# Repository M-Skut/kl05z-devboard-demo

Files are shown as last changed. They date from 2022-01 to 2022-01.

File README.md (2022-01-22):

# KL-05 DevBoard Demo project with simple HAL

## Hardware
To make development of advanced microcontroller projects simple, the DevBoard is equipped with following features:
- SD Card slot
- 6-button keypad connected as analog input
- stylophone-like keyboard as analog input
- PMOD Interface Type 2 (SPI)
- MikroBus Connector
- 3x WS2812B addressable RGB LEDs
- connector for Nokia 5510 display board
- buzzer
- fused 3V3 and 5V lines
- connector for Adafruit ALS-PT19 Analog Light Sensor Breakout
- connector for 16x2 LCD with I2C adapter
- 25LCxxx SPI Flash
- 2x 24Cxx I2C Flash
- RTC clock with battery based on PCF8563 RTC IC with I2C interface
- LM75 I2C temperature sensor

## Some photos of the hardware (more in `media` folder)

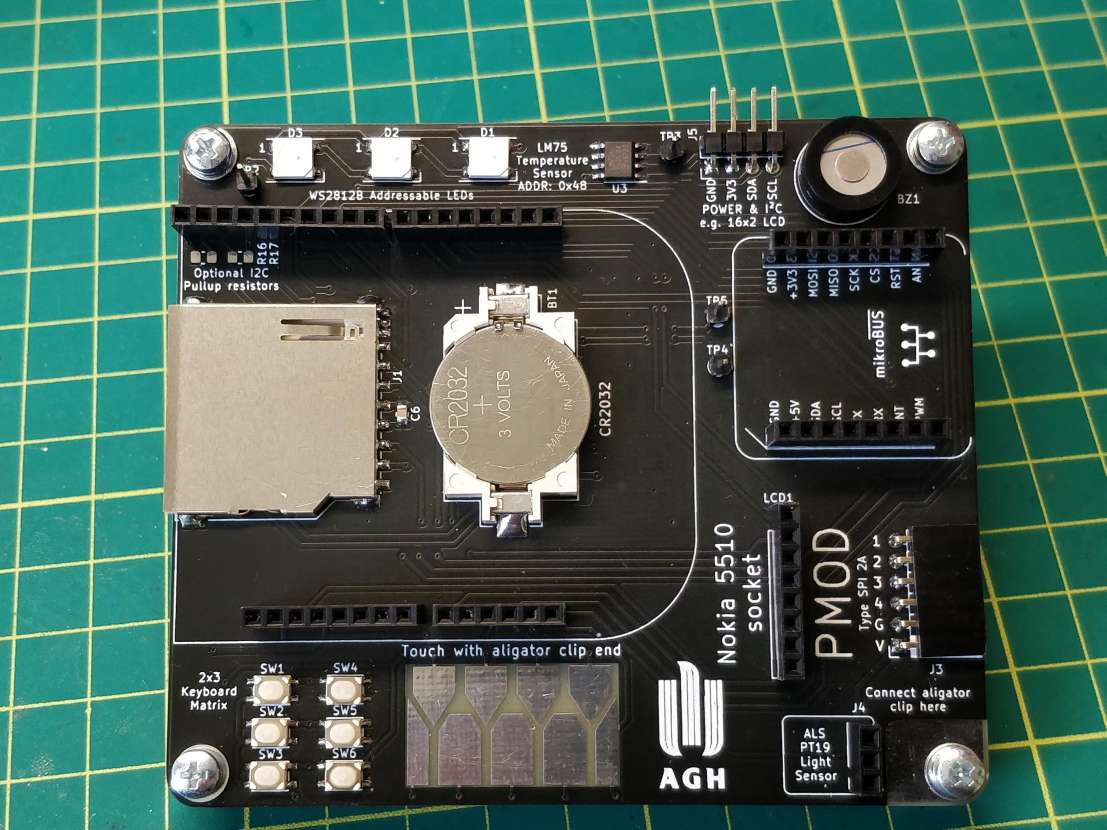
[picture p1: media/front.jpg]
Front of the PCB

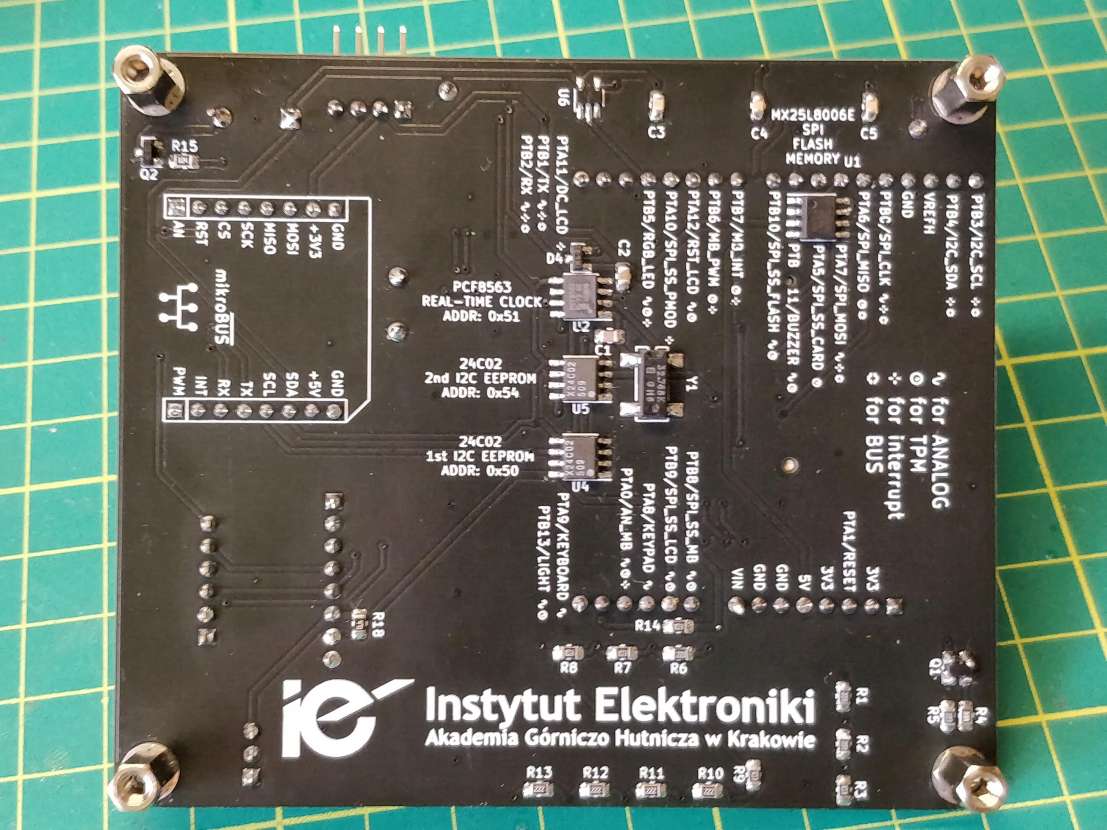
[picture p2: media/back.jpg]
Back of the PCB


## Bill Of Materials
Interactive Bill Of Materials for the newest revision of the hardware can be found [here](frdm05-devboard-hardware/bom/ibom.html)

#### Hardware revision history
Rev. 1:
- first revision of hardware
Rev. 2:
- fix for analog keypad (wrong placement of current mirror)
- addition of current-limiting resistor for buzzer
- addition of optional fuses for 3V3 and 5V lines
Rev. 2.1:
- fix for 3V3 fuse
- fix for buzzer footprint
- fix for some silkscreen areas
Rev. 2.2:
- change 74HCT1G125GV buffer to faster 74AHCT1G125GV version

## Environment
To develop this demonstration project, following set of tools and programs was used:
- [Visual Studio Code](https://code.visualstudio.com/) with plugins:
    - [`Cortex Debug`](https://marketplace.visualstudio.com/items?itemName=marus25.cortex-debug) from `marus25`
    - [`CMake Tools`](https://marketplace.visualstudio.com/items?itemName=ms-vscode.cmake-tools) from `microsoft`
- GNU GCC ARM Compiler from Official ARM Distribution
- SEGGER JLINK
- CMake
- Ninja
- (Optional) ARM Compiler 5 from Keil
- (Optional) Doxygen

### How to install it on Windows
- Install GCC from [Official ARM Distribution](https://developer.arm.com/tools-and-software/open-source-software/developer-tools/gnu-toolchain/gnu-rm/downloads) and **check "Add to PATH"** when installing
- Install [CMake](https://cmake.org/download/), also **Add to PATH** when installing
- Install [J-Link Software and Documentation pack](https://www.segger.com/downloads/jlink/)
- Download [Ninja](https://github.com/ninja-build/ninja/releases) and put it into some folder in PATH, for example in `C:\Program Files\CMake\bin`
- [Install Visual Studio Code](https://code.visualstudio.com/download) and its extensions
- (Optional) Install [Doxygen](https://www.doxygen.nl/download.html) for generating documentation

### How to install it on other operating systems
- Install the required software from author's website or from OS repositories.

Now you can open the project folder. Select GNU toolchain as CMake kit when asked and edit file `launch.json` inside `.vscode` folder if your `JLinkGDBServer` location is different than he one used in this project. For ARM Compiler 5.06 toolchain,
an environment variable `ARMCC_TOOLCHAIN_PATH` has to be set to `bin` folder of the toolchain files. Alternatively, `armcc.cmake` file inside `toolchain-conf` can be edited to make te path setting permanent.

### Environment features
- two-click switch between ARM Compiler 5 and GCC Compiler
- all code editing features that Visual Studio Code has to offer
- easy debugging of compiled code
- two-click generation of doxygen HTML documentation
- built-in git integration
- works on Windows, GNU/Linux and Mac OS (or at least should)

## HAL
This simple hardware abstraction layer is based on two sources: KL05 Sample Code Package
from Freescale and MBED platform-specific code for KLXX targets. The C API relies
on heavy use of custom enums and structs to ensure that invalid function parameters can be found in
compilation stage. It uses C99 features (`stdint.h`, `stdbool.h`, in-place struct 
initialization etc.) and was tested with GCC 11 compiler and ARM 5.06 Compiler, but should
be compiler-independent, as it does not use compiler-dependent features directly, but instead it's using
CMSIS functions as abstraction layer.

### Goals:
- Prevent user from error-prone and hard-to-debug manual peripheral register setting
- Simple and straightforward for both understanding the underlying code and using the API
- Versatile - use for all applications within this uC
- Smallish footprint
- Separated device drivers from mcu peripheral drivers (exceptions only for very timing-sensitive devices)
- User-proof, mostly
- Peripherals can be reinitialized and will still work
- Communication peripheral drivers can be used without gpio driver
- Supports any MCU working frequency 

### Non-goals:
- universal
- unified (in GPIO mapping, same peripheral but more instances etc.)

### Drivers features:
#### UART:
- different pinout configuration
- automatic calculation for baudrate with ability to re-init if CPU speed changes
- error if configuration baudrate or pins cannot be set
- simple print, putchar and getchar API
- RX IRQ callback setting and checking RX overrun

#### I2C:
- different pinout configuration
- different speed selection
- timeout detection in all functions
- included fix for silicon errata
  
#### GPIO
- bare-bones abstraction of the register setting
- interrupt with callback functions
- inline functions for fast pin setting

#### Delay
- SysTick-based delay
- works without affecting SysTick settings
- based on delay code from u8g2 project

#### ADC
- ADC calibration function
- simple 16-bit value read
- uses `gpio` driver for pin mapping
- ADC presets (currently only one available)

#### PWM
- TPM-based PWM
- uses `gpio` driver for pin mapping
- allows setting period and pulse width in microseconds or as raw values

#### WS2812
- currently only GCC supported
- based on [cpldcpu's WS2812 ARM bitbang driver](https://github.com/cpldcpu/light_ws2812/blob/master/light_ws2812_ARM/light_ws2812_cortex.c)

#### MMA8451Q
- range setting
- conversion to float values

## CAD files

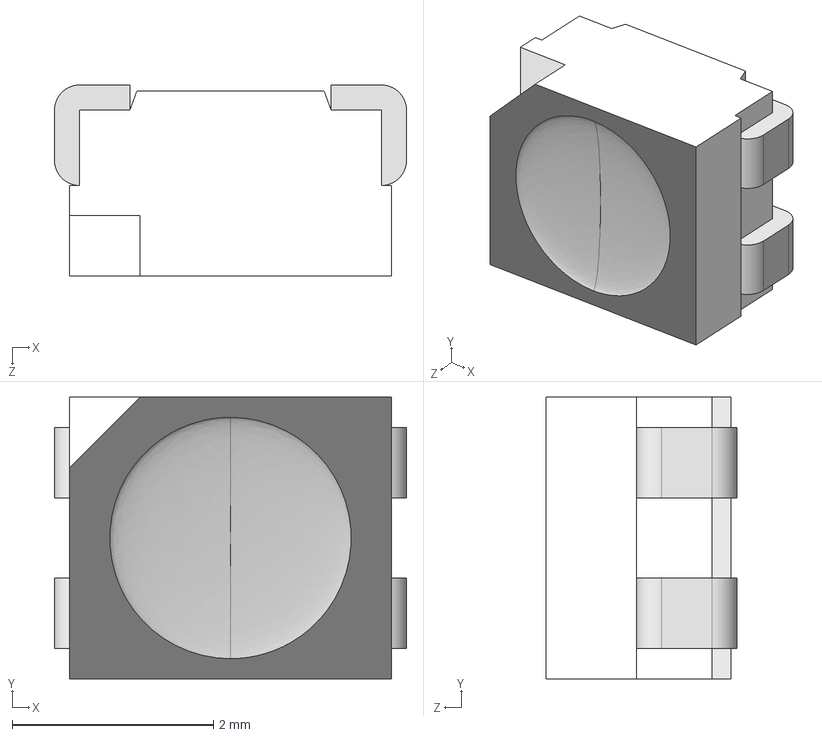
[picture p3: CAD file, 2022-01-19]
frdm05-devboard-hardware/FRDM-KL05Z-Mockup/led.step
3.50 x 2.80 x 1.90 mm

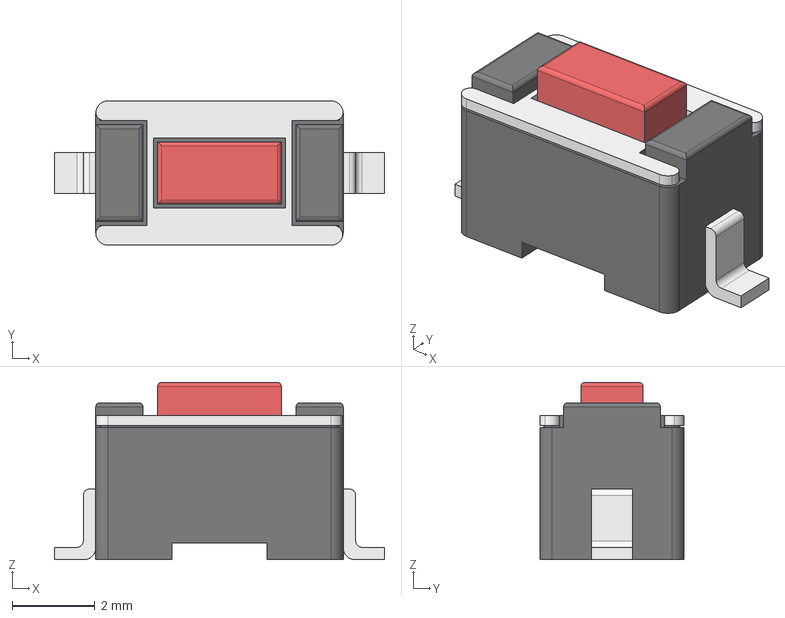
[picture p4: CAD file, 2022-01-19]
frdm05-devboard-hardware/FRDM-KL05Z-Mockup/switch.step
8.00 x 3.50 x 4.30 mm

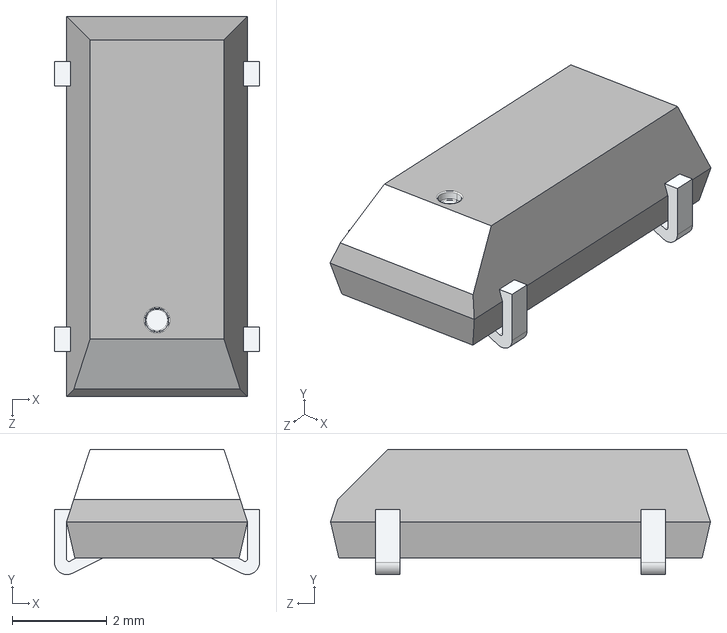
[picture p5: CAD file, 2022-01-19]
frdm05-devboard-hardware/FRDM-KL05Z-Mockup/crystal.step
4.32 x 2.63 x 8.00 mm

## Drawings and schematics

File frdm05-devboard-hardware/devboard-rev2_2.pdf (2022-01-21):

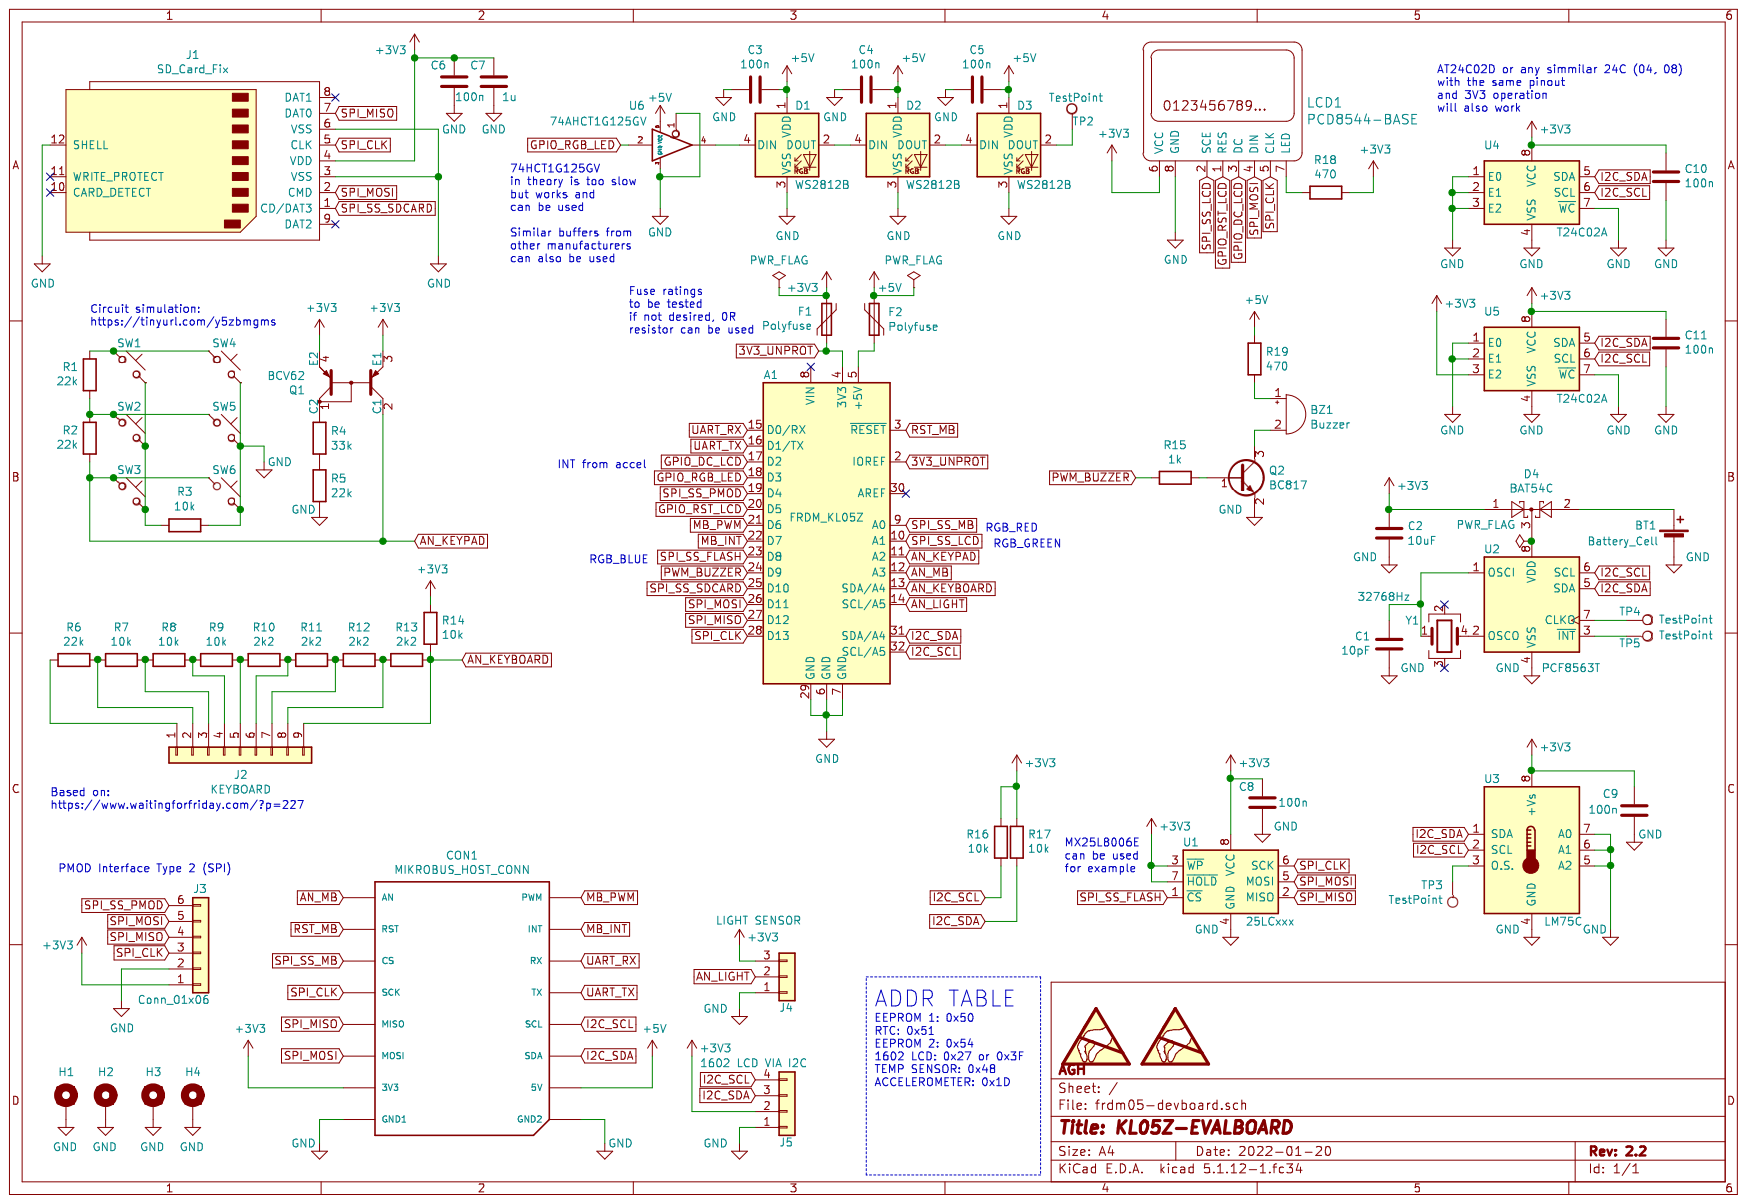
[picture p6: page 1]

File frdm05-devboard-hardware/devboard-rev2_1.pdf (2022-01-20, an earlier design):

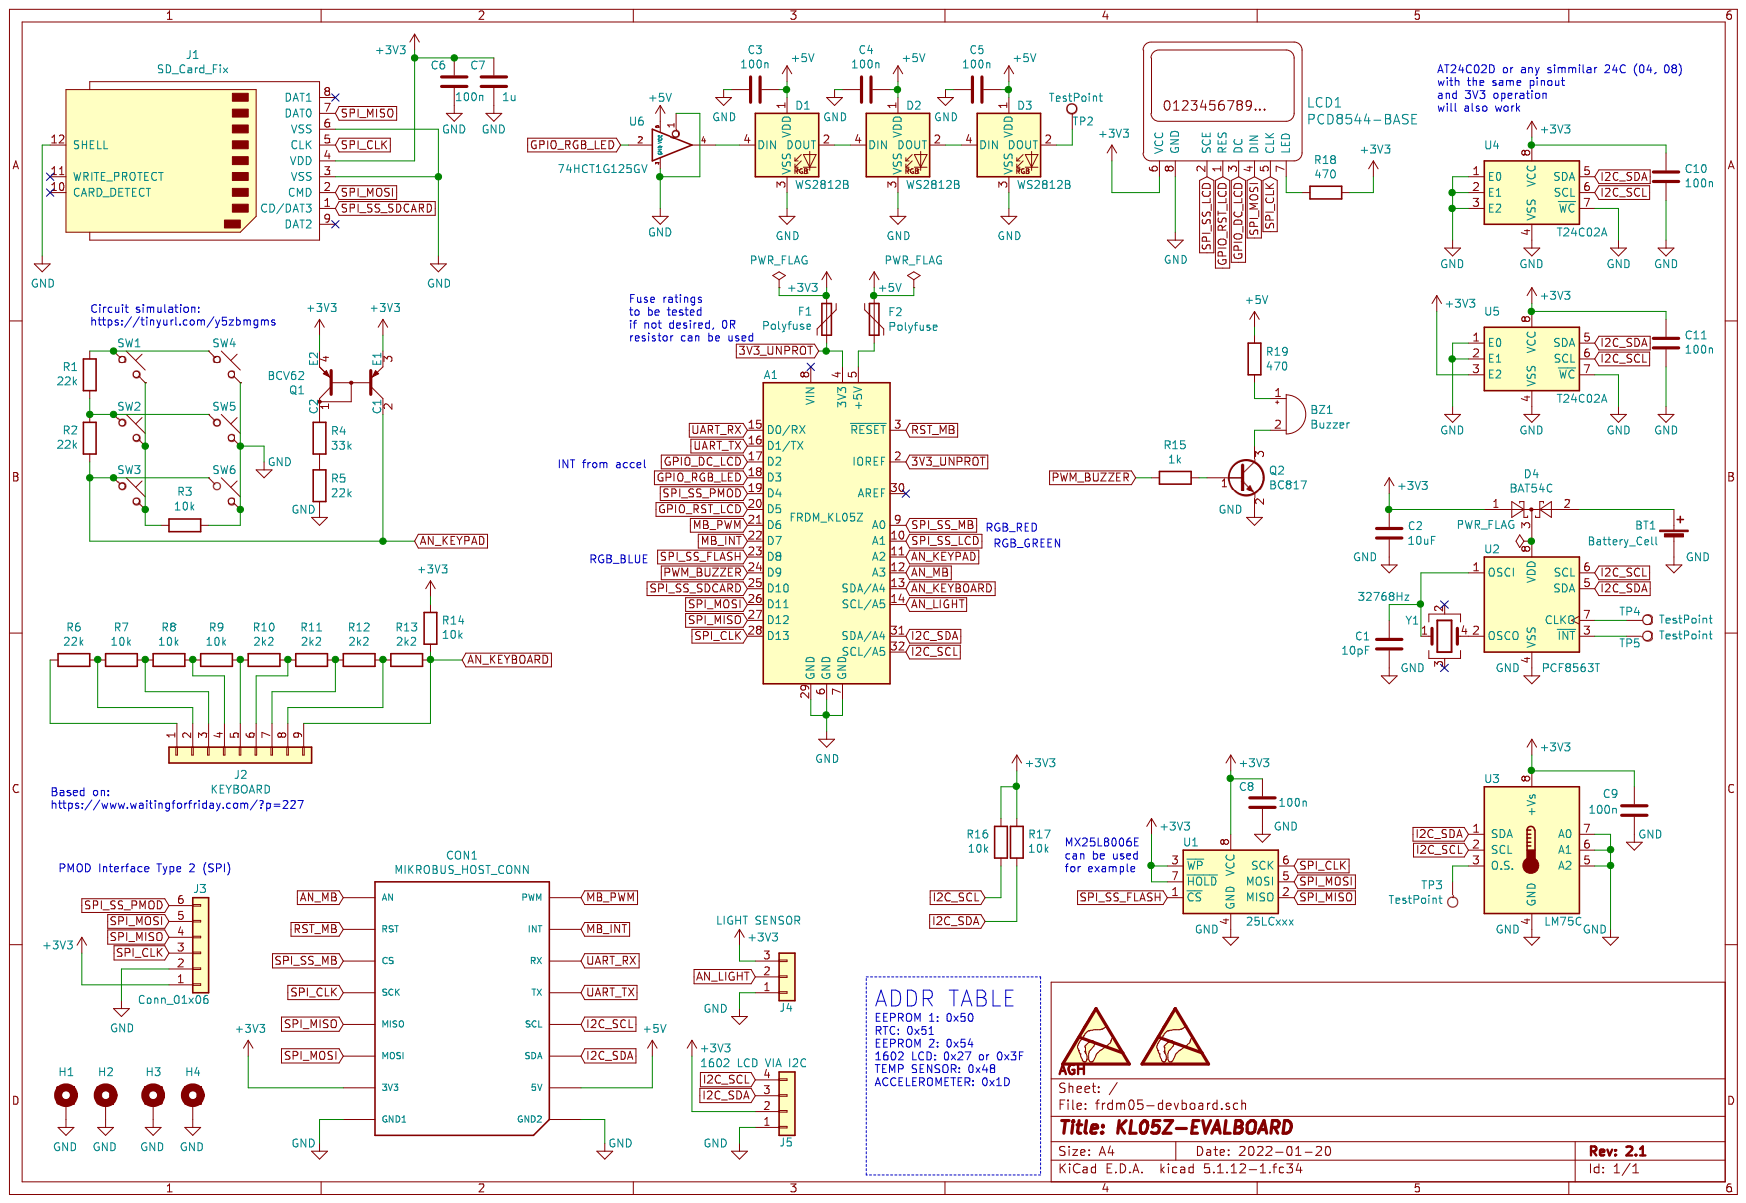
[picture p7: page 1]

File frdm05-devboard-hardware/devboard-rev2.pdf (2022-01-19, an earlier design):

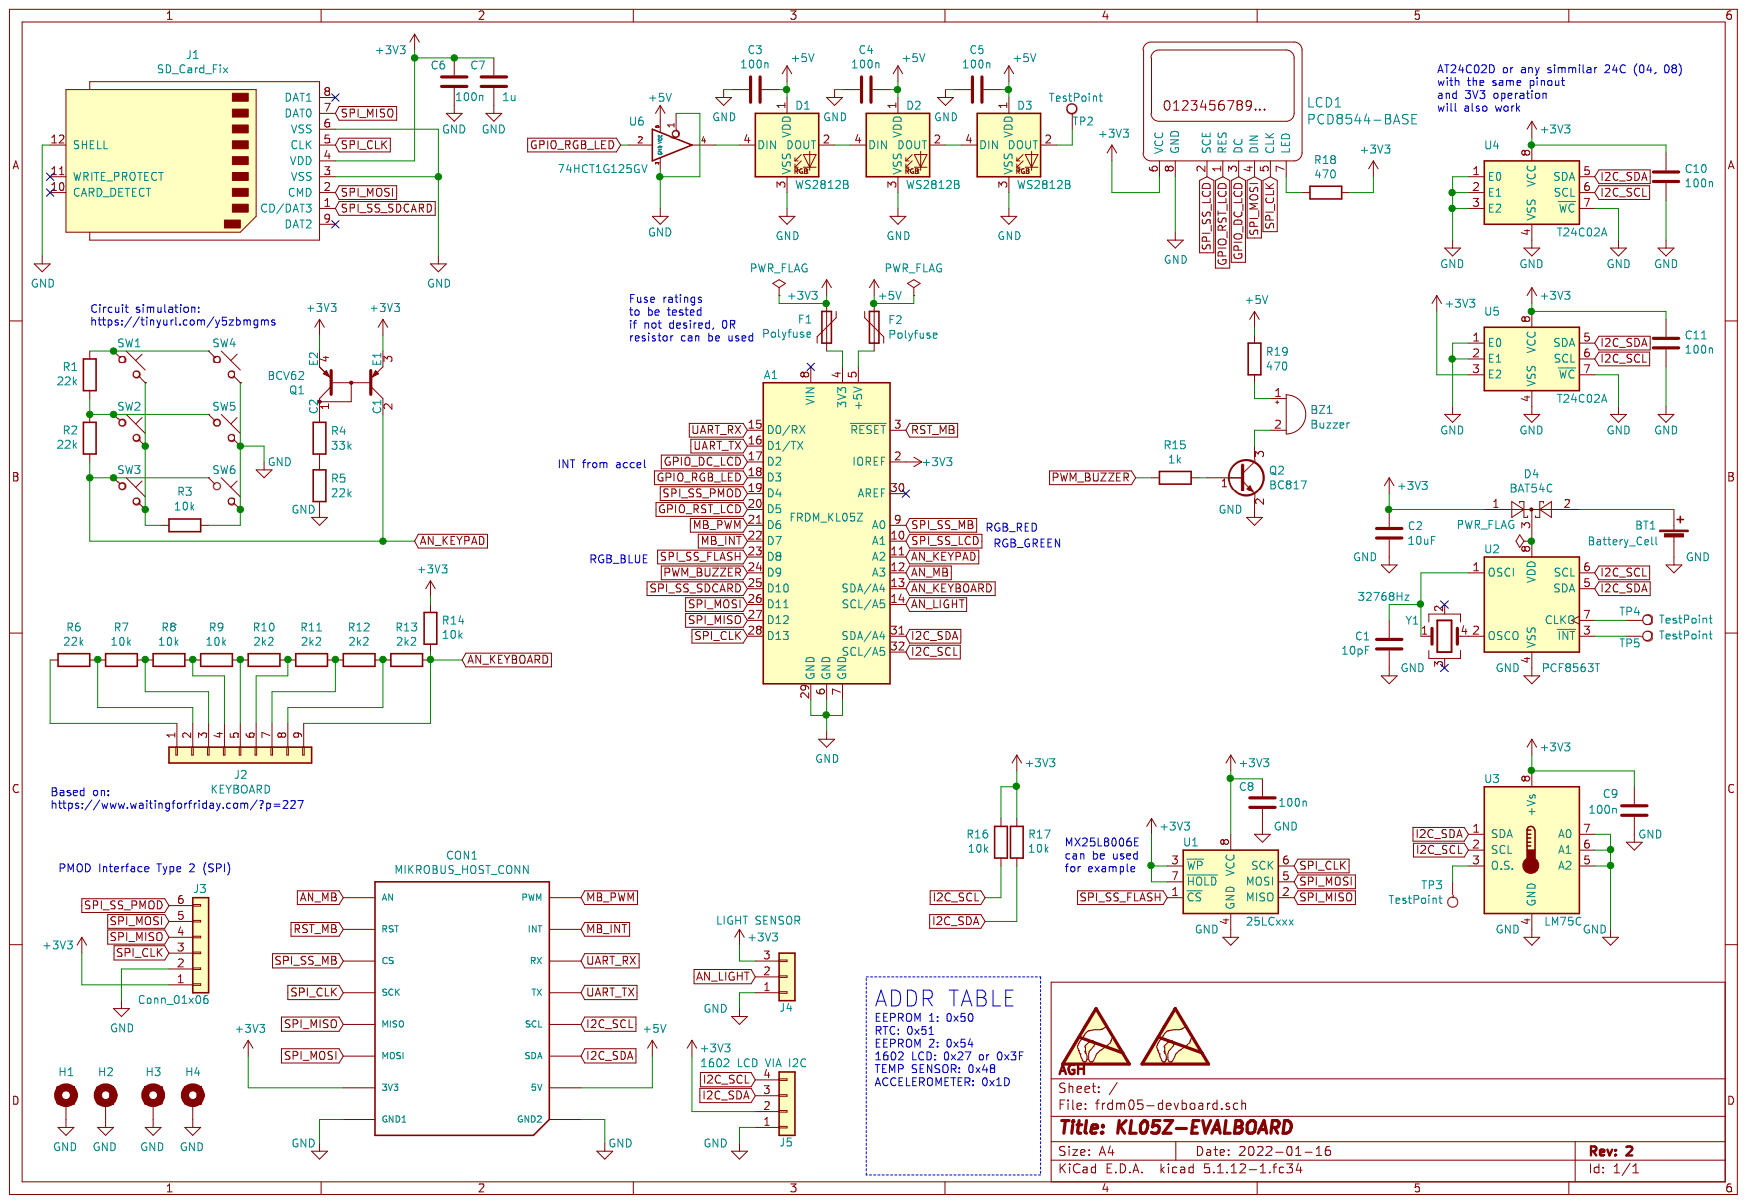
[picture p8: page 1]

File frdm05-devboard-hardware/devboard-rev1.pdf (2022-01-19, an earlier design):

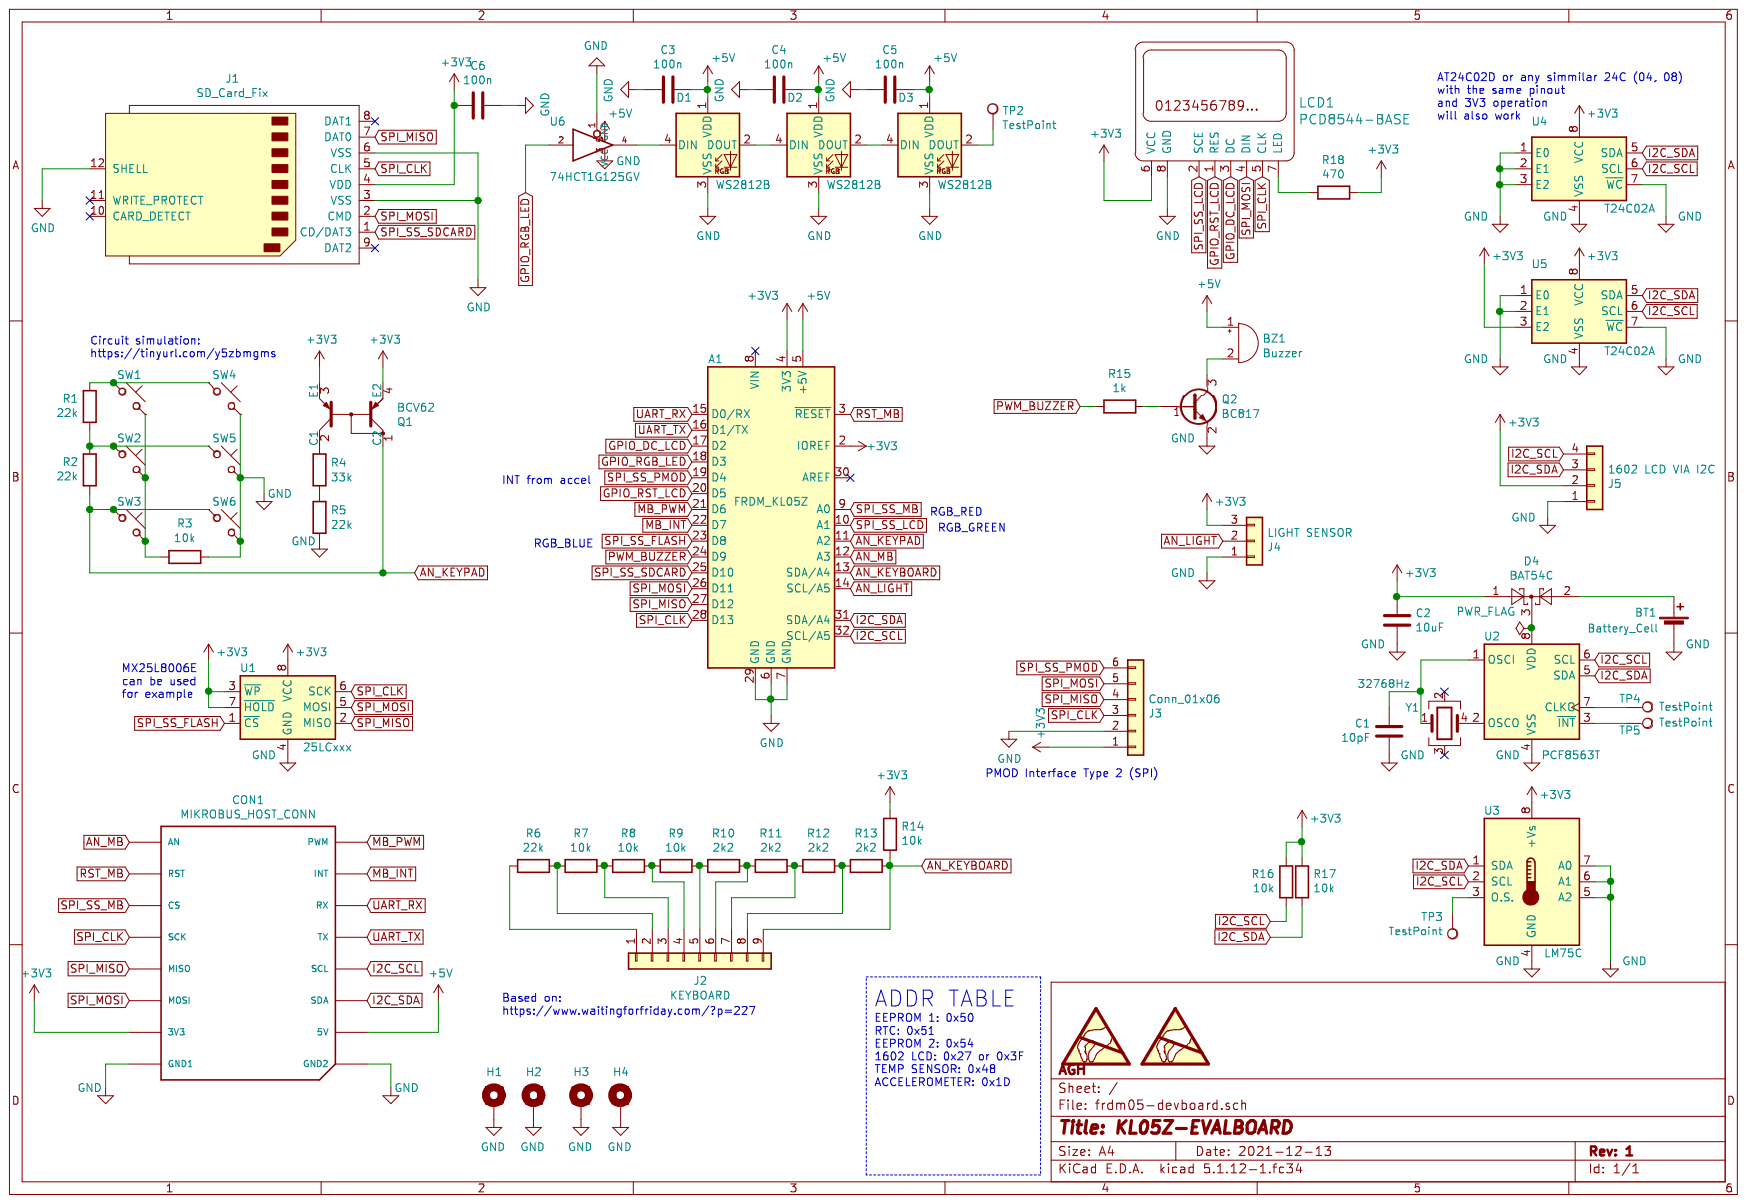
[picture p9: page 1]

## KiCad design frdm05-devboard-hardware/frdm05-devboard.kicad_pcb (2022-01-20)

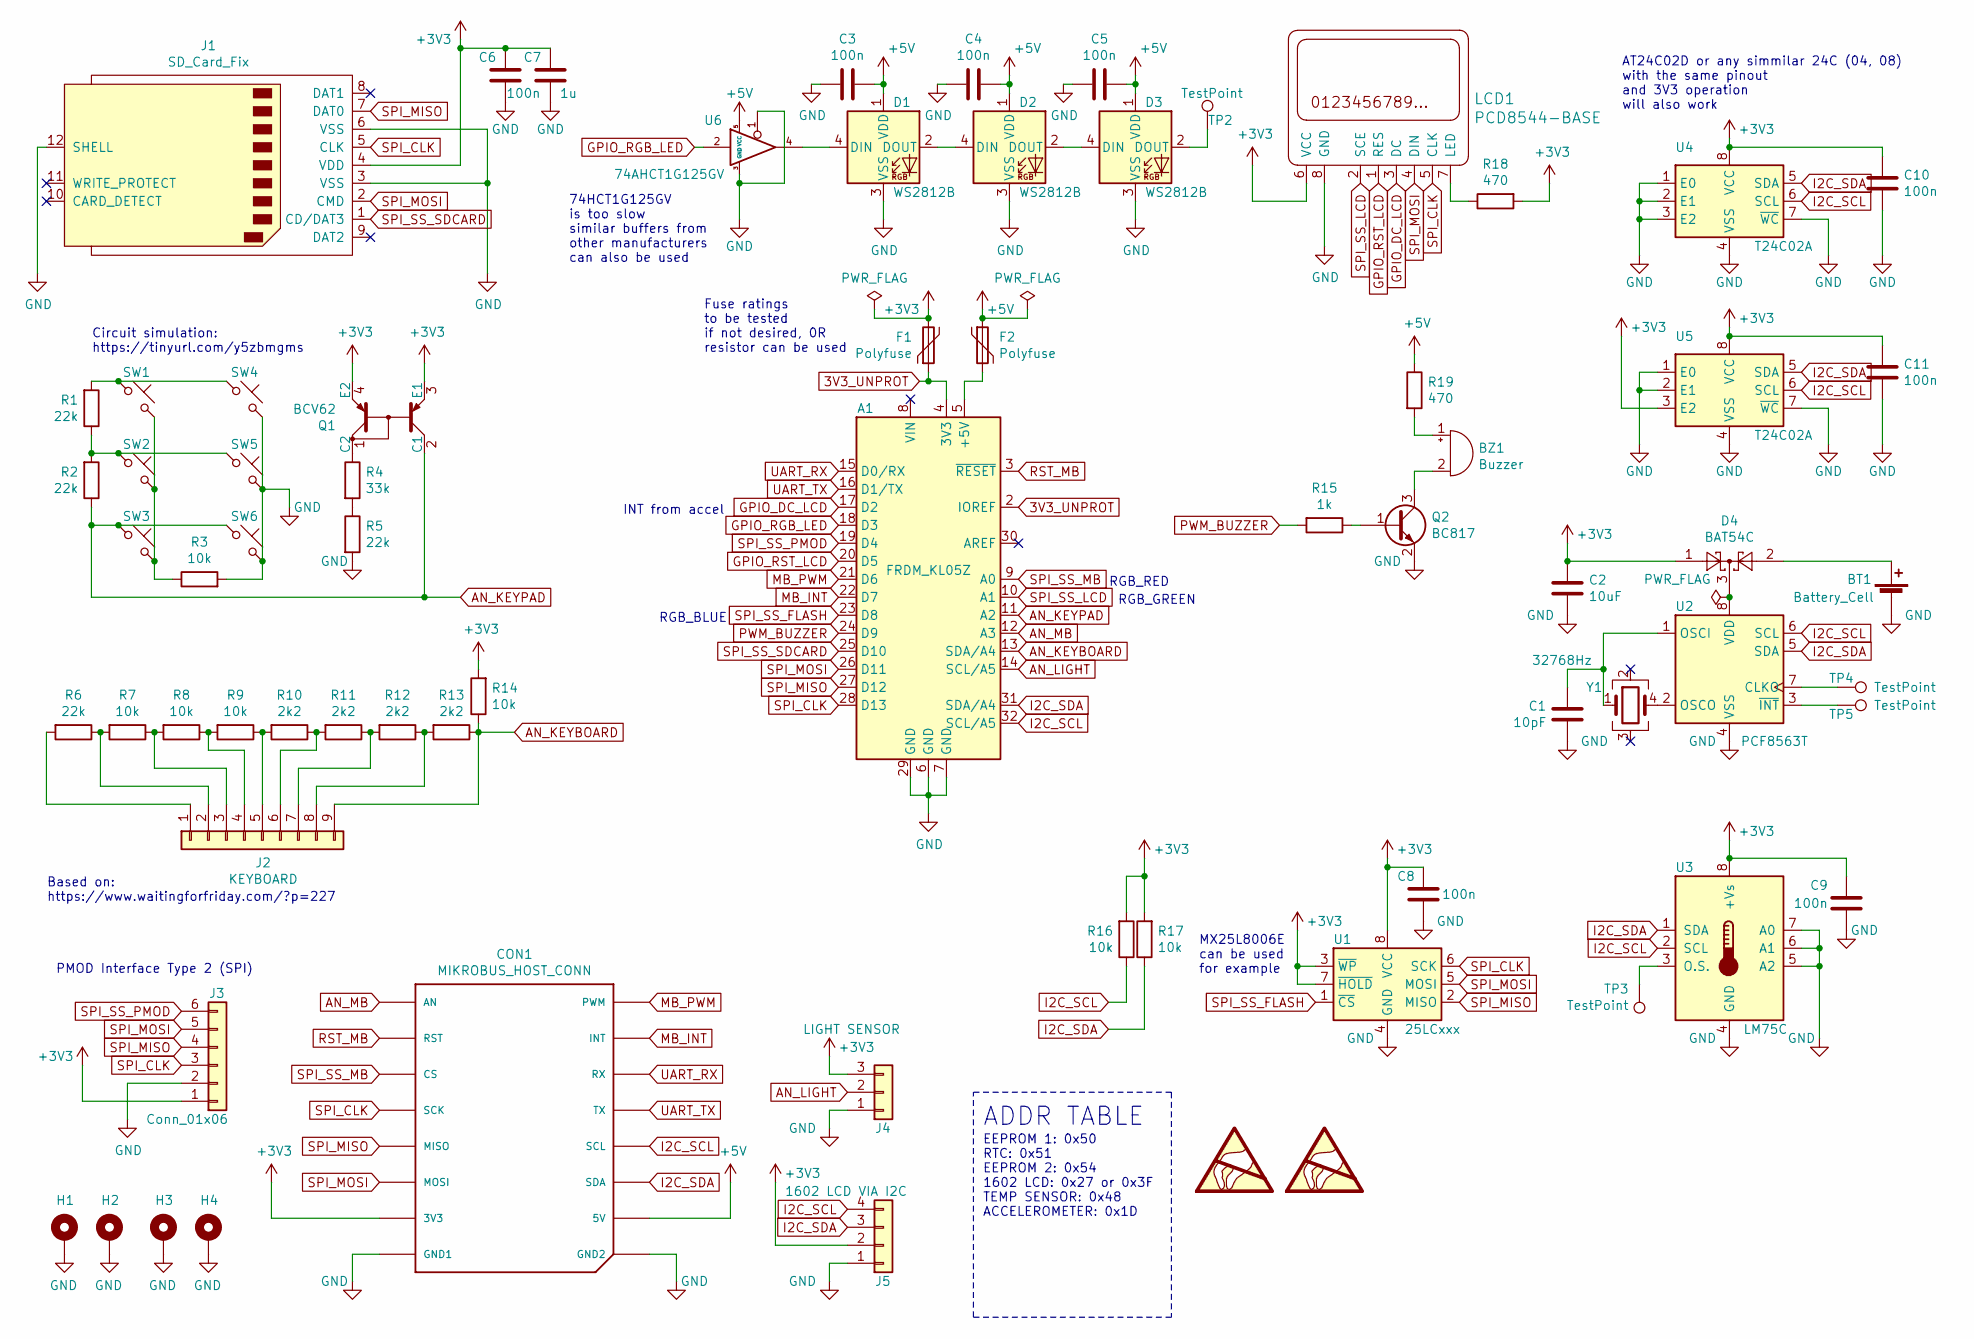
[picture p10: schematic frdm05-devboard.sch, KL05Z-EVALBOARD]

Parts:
A1: FRDM_KL05Z; FDRM-KL05Z
BT1: Battery_Cell; BatteryHolder_Keystone_1060_1x2032
BZ1: Buzzer; MagneticBuzzer_ProSignal_ABT-410-RC
C1: 10pF; C_0805_2012Metric_Pad1.18x1.45mm_HandSolder
C2: 10uF; C_0805_2012Metric_Pad1.18x1.45mm_HandSolder
C3, C4, C5, C6, C8, C9, C10, C11: 100n; C_0805_2012Metric_Pad1.18x1.45mm_HandSolder
C7: 1u; C_0805_2012Metric_Pad1.18x1.45mm_HandSolder
CON1: MIKROBUS_HOST_CONN
D1, D2, D3: WS2812B; LED_WS2812B_PLCC4_5.0x5.0mm_P3.2mm
D4: BAT54C; SOT-23
F1, F2: Polyfuse; Fuse_0805_2012Metric
H1, H2, H3, H4: MountingHole_Pad; MountingHole_3.2mm_M3_Pad_Via
J1: SD_Card_Fix; SD_TE_2041021
J2: KEYBOARD; Keyboard_resistive
J3: Conn_01x06; PinSocket_1x06_P2.54mm_Horizontal
J4: LIGHT SENSOR; PinSocket_1x03_P2.54mm_Vertical
J5: 1602 LCD VIA I2C; PinHeader_1x04_P2.54mm_Horizontal
LCD1: PCD8544-BASE; PinSocket_1x08_P2.54mm_Vertical
Q1: BCV62; SOT-143
Q2: BC817; SOT-23
R1, R2, R5, R6: 22k; R_0805_2012Metric_Pad1.20x1.40mm_HandSolder
R3, R7, R8, R9, R14, R16, R17: 10k; R_0805_2012Metric_Pad1.20x1.40mm_HandSolder
R4: 33k; R_0805_2012Metric_Pad1.20x1.40mm_HandSolder
R10, R11, R12, R13: 2k2; R_0805_2012Metric_Pad1.20x1.40mm_HandSolder
R15: 1k; R_0805_2012Metric_Pad1.20x1.40mm_HandSolder
R18, R19: 470; R_0805_2012Metric_Pad1.20x1.40mm_HandSolder
SW1, SW2, SW3, SW4, SW5, SW6: PTS810; SW_SPST_PTS810_HandSoldering
SYM1: SYM_ESD_Large; agieh
SYM2: SYM_ESD_Large; prestiz
TP2, TP3, TP4, TP5: TestPoint; TestPoint_THTPad_D2.0mm_Drill1.0mm
U1: 25LCxxx; SOIC-8_3.9x4.9mm_P1.27mm
U2: PCF8563T; SOIC-8_3.9x4.9mm_P1.27mm
U3: LM75C; SOIC-8_3.9x4.9mm_P1.27mm
U4, U5: T24C02A; SOIC-8_3.9x4.9mm_P1.27mm
U6: 74AHCT1G125GV; SOT-23-5_HandSoldering
Y1: 32768Hz; Crystal_SMD_SeikoEpson_MC306-4Pin_8.0x3.2mm_HandSoldering

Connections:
3V3_UNPROT: A1.2 (IOREF), A1.4 (3V3), F1.1
+3V3: C2.1, C6.2, C7.2, C8.1, C9.2, C10.2, C11.2, CON1.P7 (3V3), D4.1, F1.2, J1.4 (VDD), J3.1, J4.3, J5.2, LCD1.6 (VCC), Q1.3 (E1), Q1.4 (E2), R14.2, R16.2, R17.2, R18.2, U1.3 (~WP), U1.7 (~HOLD), U1.8 (VCC), U3.8 (+Vs), U4.8 (VCC), U5.3 (E2), U5.8 (VCC)
+5V: C3.1, C4.1, C5.1, CON1.P10 (5V), D1.1 (VDD), D2.1 (VDD), D3.1 (VDD), F2.1, R19.1, U6.5 (VCC)
AN_KEYBOARD: A1.13 (SDA/A4), J2.9, R13.1, R14.1
AN_KEYPAD: A1.11 (A2), Q1.2 (C1), R2.1, SW3.1, SW6.1
AN_LIGHT: A1.14 (SCL/A5), J4.2
AN_MB: A1.12 (A3), CON1.P1 (AN)
GND: A1.6 (GND), A1.7 (GND), A1.29 (GND), BT1.2 (-), C1.1, C2.2, C3.2, C4.2, C5.2, C6.1, C7.1, C8.2, C9.1, C10.1, C11.1, CON1.P8 (GND1), CON1.P9 (GND2), D1.3 (VSS), D2.3 (VSS), D3.3 (VSS), H1.1, H2.1, H3.1, H4.1, J1.3 (VSS), J1.6 (VSS), J1.12 (SHELL), J3.2, J4.1, J5.1, LCD1.8 (GND), Q2.2 (E), R3.2, R5.2, SW4.2, SW5.2, SW6.2, U1.4 (GND), U2.4 (VSS), U3.4 (GND), U3.5 (A2), U3.6 (A1), U3.7 (A0), U4.1 (E0), U4.2 (E1), U4.3 (E2), U4.4 (VSS), U4.7 (~WC), U5.1 (E0), U5.2 (E1), U5.4 (VSS), U5.7 (~WC), U6.1, U6.3 (GND)
GPIO_DC_LCD: A1.17 (D2), LCD1.3 (DC)
GPIO_RGB_LED: A1.18 (D3), U6.2
GPIO_RST_LCD: A1.20 (D5), LCD1.1 (RES)
I2C_SCL: A1.32 (SCL/A5), CON1.P12 (SCL), J5.4, R16.1, U2.6 (SCL), U3.2 (SCL), U4.6 (SCL), U5.6 (SCL)
I2C_SDA: A1.31 (SDA/A4), CON1.P11 (SDA), J5.3, R17.1, U2.5 (SDA), U3.1 (SDA), U4.5 (SDA), U5.5 (SDA)
MB_INT: A1.22 (D7), CON1.P15 (INT)
MB_PWM: A1.21 (D6), CON1.P16 (PWM)
unnamed: A1.5 (+5V), F2.2
unnamed: BT1.1 (+), D4.2
unnamed: BZ1.1 (-), R19.2
unnamed: BZ1.2 (+), Q2.3 (C)
unnamed: C1.2, U2.1 (OSCI), Y1.1
unnamed: D1.2 (DOUT), D2.4 (DIN)
unnamed: D1.4 (DIN), U6.4
unnamed: D2.2 (DOUT), D3.4 (DIN)
unnamed: D3.2 (DOUT), TP2.1
unnamed: D4.3, U2.8 (VDD)
unnamed: J2.1, R6.2
unnamed: J2.2, R6.1, R7.2
unnamed: J2.3, R7.1, R8.2
unnamed: J2.4, R8.1, R9.2
unnamed: J2.5, R9.1, R10.2
unnamed: J2.6, R10.1, R11.2
unnamed: J2.7, R11.1, R12.2
unnamed: J2.8, R12.1, R13.2
unnamed: LCD1.7 (LED), R18.1
unnamed: Q1.1 (C2), R4.1
unnamed: Q2.1 (B), R15.1
unnamed: R1.1, R2.2, SW2.1, SW5.1
unnamed: R1.2, SW1.1, SW4.1
unnamed: R3.1, SW1.2, SW2.2, SW3.2
unnamed: R4.2, R5.1
unnamed: TP3.1, U3.3 (O.S.)
unnamed: TP4.1, U2.7 (CLKO)
unnamed: TP5.1, U2.3 (~INT~)
unnamed: U2.2 (OSCO), Y1.4
PWM_BUZZER: A1.24 (D9), R15.2
RST_MB: A1.3 (~RESET), CON1.P2 (RST)
SPI_CLK: A1.28 (D13), CON1.P4 (SCK), J1.5 (CLK), J3.3, LCD1.5 (CLK), U1.6 (SCK)
SPI_MISO: A1.27 (D12), CON1.P5 (MISO), J1.7 (DAT0), J3.4, U1.2 (MISO)
SPI_MOSI: A1.26 (D11), CON1.P6 (MOSI), J1.2 (CMD), J3.5, LCD1.4 (DIN), U1.5 (MOSI)
SPI_SS_FLASH: A1.23 (D8), U1.1 (~CS)
SPI_SS_LCD: A1.10 (A1), LCD1.2 (SCE)
SPI_SS_MB: A1.9 (A0), CON1.P3 (CS)
SPI_SS_PMOD: A1.19 (D4), J3.6
SPI_SS_SDCARD: A1.25 (D10), J1.1 (CD/DAT3)
UART_RX: A1.15 (D0/RX), CON1.P14 (RX)
UART_TX: A1.16 (D1/TX), CON1.P13 (TX)

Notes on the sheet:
Circuit simulation: https://tinyurl.com/y5zbmgms
Based on: https://www.waitingforfriday.com/?p=227
AT24C02D or any simmilar 24C (04, 08) with the same pinout and 3V3 operation will also work
MX25L8006E can be used for example
ADDR TABLE
EEPROM 1: 0x50 RTC: 0x51 EEPROM 2: 0x54 1602 LCD: 0x27 or 0x3F TEMP SENSOR: 0x48 ACCELEROMETER: 0x1D
RGB_RED
RGB_GREEN
RGB_BLUE
INT from accel
PMOD Interface Type 2 (SPI)
Fuse ratings to be tested if not desired, 0R resistor can be used
74HCT1G125GV is too slow similar buffers from other manufacturers can also be used

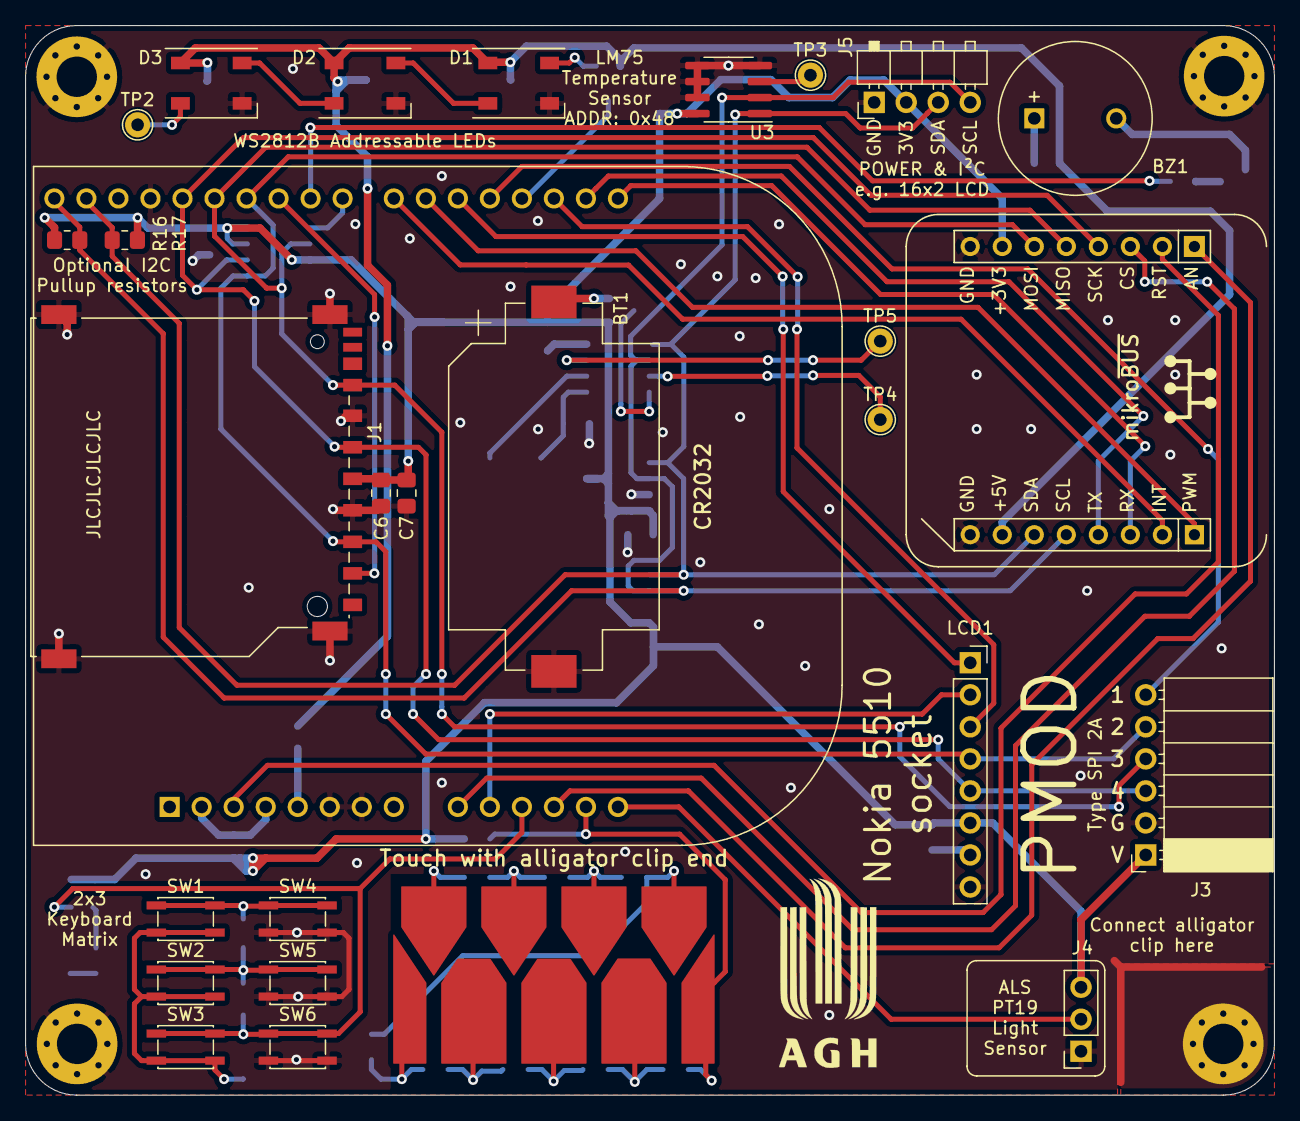
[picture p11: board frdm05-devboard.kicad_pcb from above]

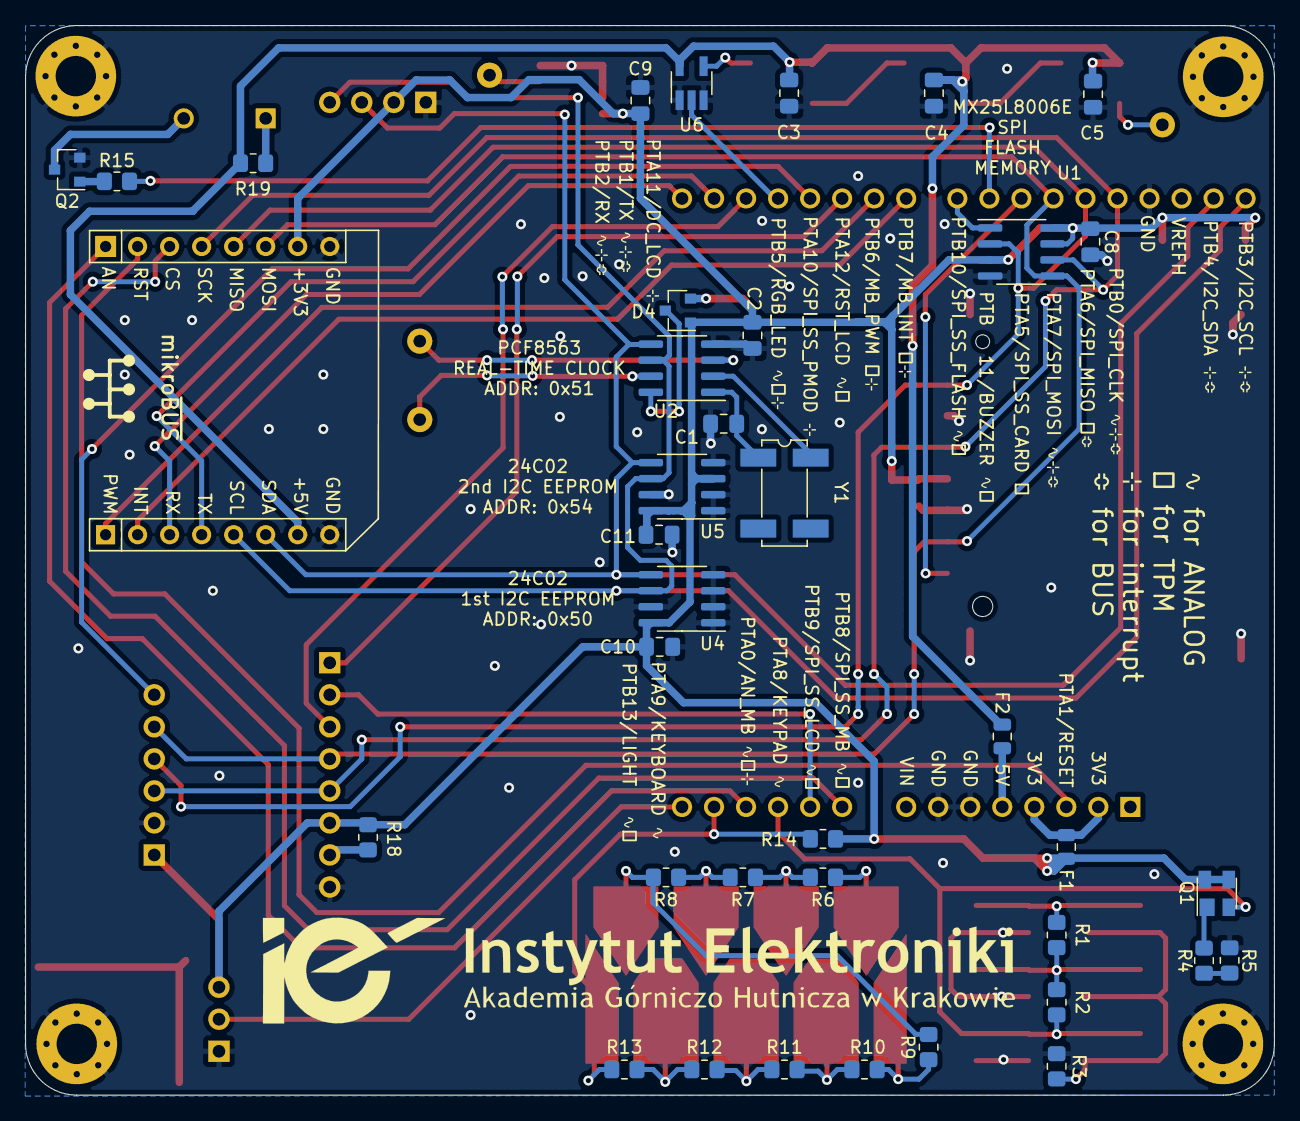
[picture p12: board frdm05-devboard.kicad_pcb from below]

Board: 2 copper layers, 99.1 x 84.8 mm, 71 parts (38 on the bottom side), 56 nets.

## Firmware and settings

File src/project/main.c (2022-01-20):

#include <stdint.h>

#include "MKL05Z4.h"
#include "cmdline.h"
#include "delay.h"
#include "error_handler.h"
#include "i2c.h"
#include "microrl.h"
#include "spi.h"
#include "u8x8.h"
#include "u8x8_mkl_hal.h"
#include "uart.h"

microrl_t rl;
microrl_t* prl = &rl;

/** Usage of the prompt
 * In putty -> terminal check "implicit Cr in every LF" and "implicit LF in every CF"
 * In picocom use imap for example: picocom -b 9600 /dev/ttyACM0 --imap crcrlf
 */

int main()
{
    delay_init();
    if (uart_init(9600, UART_PTB2_RX, UART_PTB1_TX) != UART_OK)
        display_error();
    if (i2c_init(I2C_PTB3_SCL, I2C_PTB4_SDA, 100000) != I2C_OK)
        display_error();
    if (spi_init(SPI_MODE_0, 1000000, SPI_SIDE_MASTER) != SPI_OK)
        display_error();

    cmdline_init(prl);

    while (1) {
        process_uart();
    }
}

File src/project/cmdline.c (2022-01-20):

#include "ftoa.h"
#include <stdint.h>
#include <stdio.h>
#include <stdlib.h>
#include <string.h>

#include "MKL05Z4.h"

#include "adc.h"
#include "cmdline.h"
#include "delay.h"
#include "gpio.h"
#include "i2c.h"
#include "mma8451q.h"
#include "pwm.h"
#include "spi.h"
#include "u8x8.h"
#include "u8x8_mkl_hal.h"
#include "uart.h"
#include "ws2812b.h"

#include "config.h"
#include "microrl.h"

#define CMD_HELP "help"
#define CMD_CLEAR "clear"
#define CMD_I2C "i2c"
#define CMD_SPI "spi"
#define CMD_LED "led"
#define CMD_PWMTEST "pwmtest"
#define CMD_ADC "adc"

#define SUBCMD_MMA_TEST "mma_test"
#define SUBCMD_MMA_READALL "mma_read_all"
#define SUBCMD_I2C_BUSSCAN "busscan"
#define SUBCMD_SPI_TEST "display_test"
#define SUBCMD_LED_TEST "test"

#define SUBCMD_ADC_INIT "init"
#define SUBCMD_ADC_READ "read"
#define SUBCMD_ADC_KPAD_TEST "keypad_test"
#define SUBCMD_ADC_KB_TEST "keyboard_test"
#define SUBCMD_ADC_STYLO_DEMO "stylophone_demo"

#define NUM_OF_CMD 7
#define NUM_OF_I2C_SCMD 3
#define NUM_OF_SPI_SCMD 1
#define NUM_OF_LED_SCMD 1
#define NUM_OF_ADC_SCMD 5

// Internal microrl pointer
static microrl_t* prl = NULL;

// Char for adding new char to microrl to avoid running everything
// in interrupt context
static volatile bool new_char = false;
static volatile uint8_t new_char_data = 0;

// u8x8 struct
u8x8_t u8x8;

bool run_task = false;

static char string_buffer[10] = { 0 };
static uint8_t mma_init_done = 0;
static mma8451q mma;

//available  commands
char* keyworld[] = { CMD_HELP, CMD_CLEAR, CMD_I2C, CMD_SPI, CMD_LED, CMD_PWMTEST, CMD_ADC };
char* i2c_subcommands[] = { SUBCMD_MMA_TEST, SUBCMD_MMA_READALL, SUBCMD_I2C_BUSSCAN };
char* spi_subcommands[] = { SUBCMD_SPI_TEST };
char* led_subcommands[] = { SUBCMD_LED_TEST };
char* adc_subcommands[] = { SUBCMD_ADC_INIT, SUBCMD_ADC_READ, SUBCMD_ADC_KPAD_TEST, SUBCMD_ADC_KB_TEST, SUBCMD_ADC_STYLO_DEMO };

// array for comletion
char* compl_world[NUM_OF_CMD + 1];

void print_help(void)
{
    uart_print("Use TAB key for completion\n\rCommand:\n\r");
    uart_print("\tclear               - clear screen\n");
    uart_print("\ti2c                 - I2C driver commands\n");
    uart_print("\tspi                 - SPI driver commands\n");
    uart_print("\tled                 - WS2812B commands\n");
    uart_print("\tpwmtest             - Test of PWM peripheral\n");
    uart_print("\tadc                 - ADC driver commands\n");

}

void i2c_busscan(void)
{
    uart_print("I2C bus scan results: \r\n");
    for (uint8_t addr = 1; addr <= 127; addr++) {
        i2c_status_t restult = i2c_ping(addr);
        if (restult == I2C_OK) {
            uart_print("Found device: ");
            sprintf(string_buffer, "%02x\r\n", addr);
            uart_print(string_buffer);
        }
    }
}

void mma_test(void)
{
    uart_print("Testing MMA8451Q accelerometer\r\n");
    mma8451_status_t mma_result = mma8451_init(&mma, MMA8451_DEFAULT_ADDRESS);
    if (mma_result)
        uart_print("MMA8451Q init failed\r\n");
    else {
        uart_print("MMA8451 init completed\r\n");
        mma_init_done = 1;
    }
}

void mma_readall(void)
{
    mma8451_status_t mma_result;
    float tmp = 0.0;
    if (!mma_init_done) {
        mma_result = mma8451_init(&mma, MMA8451_DEFAULT_ADDRESS);
        if (mma_result)
            uart_print("MMA8451Q init failed\r\n");
        mma_init_done = 1;
    }
    mma_result = mma8451_read(&mma);
    if (mma_result)
        uart_print("MMA8451Q read failed\r\n");
    uart_print("\r\nX: ");
    tmp = mma8451_get_x(&mma);
    ftoa(tmp, string_buffer, 2);
    uart_print(string_buffer);
    uart_print("\r\nY: ");
    tmp = mma8451_get_y(&mma);
    ftoa(tmp, string_buffer, 2);
    uart_print(string_buffer);
    uart_print("\r\nZ: ");
    tmp = mma8451_get_z(&mma);
    ftoa(tmp, string_buffer, 2);
    uart_print(string_buffer);
    uart_print("\r\n");
}

void spi_test(void)
{
    uart_print("Testing SPI Display\r\n");
    u8x8_Setup(&u8x8, u8x8_d_pcd8544_84x48, u8x8_cad_001, u8x8_byte_mkl05_hw_spi, u8x8_gpio_and_delay_mkl05);
    u8x8_InitDisplay(&u8x8);
    u8x8_SetPowerSave(&u8x8, 0);
    u8x8_ClearDisplay(&u8x8);
    u8x8_SetFont(&u8x8, u8x8_font_amstrad_cpc_extended_f);
    u8x8_DrawString(&u8x8, 0, 0, "Display");
    u8x8_DrawString(&u8x8, 0, 2, "Test");
}

void led_test(void)
{
    uart_print("Testing WS2811B LEDs \r\n");
    gpio_pin_t rgb_led = { PORTB, GPIOB, 5 };
    ws2812b_init(rgb_led);
    uint8_t data[] = { 0xFF, 0x00, 0x00,
        0x00, 0xFF, 0x00,
        0x00, 0x00, 0xFF };
    ws2812b_write(rgb_led, data, 9);
}

void pwm_test(void)
{
    uart_print("Testing PWM \r\n");
    gpio_pin_t green_led = { PORTB, GPIOB, 9 };
    pwm_pin_t green_led_pwm = pwm_from_gpio(green_led);
    if (pwm_init(green_led, green_led_pwm)) {
        uart_print("PWM config failed\r\n");
        return;
    }
    for (uint8_t i = 100; i > 0; i--) {
        pwm_pulsewidth_us(green_led_pwm, i * 200);
        delay_micro_seconds(10000);
    }
    for (uint8_t i = 0; i <= 100; i++) {
        pwm_pulsewidth_us(green_led_pwm, i * 200);
        delay_micro_seconds(10000);
    }
    //     gpio_pin_t red_led = {PORTB, GPIOB, 8};
    //     gpio_pin_init(red_led, GPIO_OUTPUT, GPIO_MUX_ALT1);
    //     gpio_fast_off(red_led);
    //     delay_micro_seconds(1000000);
    //     gpio_fast_on(red_led);
    //     delay_micro_seconds(1000000);
}

void adc_test_init(void)
{
    gpio_pin_t adc_a0_pin = { PORTB, GPIOB, 13 };
    adc_pin_t adc_a0 = adc_from_gpio(adc_a0_pin);
    adc_status_t cal_result = adc_init(adc_a0_pin, adc_a0, ADC_CONFIG_LOWPOWER_FAST);
    if (cal_result)
        uart_print("ADC init failed\r\n");
    else {
        uart_print("ADC init completed\r\n");
    }
}

void adc_test_read(void)
{
    gpio_pin_t adc_a0_pin = { PORTB, GPIOB, 13 };
    adc_pin_t adc_a0 = adc_from_gpio(adc_a0_pin);
    uint16_t val = adc_read(adc_a0);
    uart_print("\r\n ADC Read: ");
    sprintf(string_buffer, "%d\r\n", val);
    uart_print(string_buffer);
}

void adc_print_on_display(gpio_pin_t adc_pin)
{
    uart_print("\r\n Starting display loop, press Ctrl-C to stop \r\n");
    adc_pin_t adc_channel = adc_from_gpio(adc_pin);
    adc_init(adc_pin, adc_channel, ADC_CONFIG_LOWPOWER_FAST);
    u8x8_Setup(&u8x8, u8x8_d_pcd8544_84x48, u8x8_cad_001, u8x8_byte_mkl05_hw_spi, u8x8_gpio_and_delay_mkl05);
    u8x8_InitDisplay(&u8x8);
    u8x8_SetPowerSave(&u8x8, 0);
    u8x8_ClearDisplay(&u8x8);
    u8x8_SetFont(&u8x8, u8x8_font_amstrad_cpc_extended_f);
    run_task = true;
    uint16_t adc_val = 0;
    while (run_task) {
        u8x8_ClearDisplay(&u8x8);
        u8x8_DrawString(&u8x8, 0, 0, "ADC Value:");
        adc_val = adc_read(adc_channel);
        sprintf(string_buffer, "%d", adc_val);
        u8x8_DrawString(&u8x8, 0, 2, string_buffer);
        for (uint32_t i = 0; i < (100 * 10000); i++)
            __NOP();
    }
}
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

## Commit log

2022-01-19 Initial commit of Rev.1 hardware
    [KL05Z-Mockup.kicad_pcb, KL05Z-Mockup.sch, crystal.step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]
2022-01-19 Initial commit of Rev.2 hardware
    [frdm05-devboard-B_Cu.gbr, frdm05-devboard-B_Mask.gbr, frdm05-devboard-B_SilkS.gbr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]
2022-01-20 Initial commit of Rev.2.1 hardware
    [frdm05-devboard-B_Cu.gbr, frdm05-devboard-B_Mask.gbr, frdm05-devboard-B_SilkS.gbr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]
2022-01-20 Initial commit of Rev.2.2 hardware
    [frdm05-devboard-B_Cu.gbr, frdm05-devboard-B_Mask.gbr, frdm05-devboard-B_SilkS.gbr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]
2022-01-20 Add description for other drivers
2022-01-21 Fix note about using alternative buffer for WS2812B LEDs
    [frdm05-devboard.sch]
2022-01-22 Added photos of Rev. 1 PCB
